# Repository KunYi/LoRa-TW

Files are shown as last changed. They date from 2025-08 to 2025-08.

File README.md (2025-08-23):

# LoRa-TW

**LoRa-TW** is a hardware project designed in **KiCAD** targeting LoRa applications in the Taiwan frequency band(AS923, 920MHz ~ 925MHz).
The design is based on the **Semtech SX1262** transceiver, optimized for robust operation in noisy RF environments.

## Project Purpose
This project aims to provide a reliable LoRa module reference design for Taiwan (center frequency **922.5 MHz**).
To improve receiver robustness, an external **SAW filter** is introduced in the RX path to mitigate interference from nearby cellular communication bands.

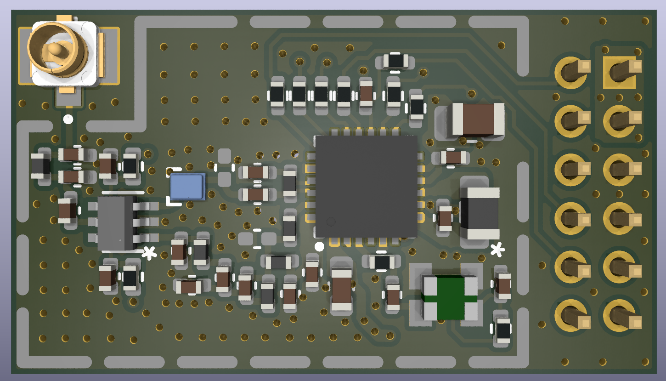
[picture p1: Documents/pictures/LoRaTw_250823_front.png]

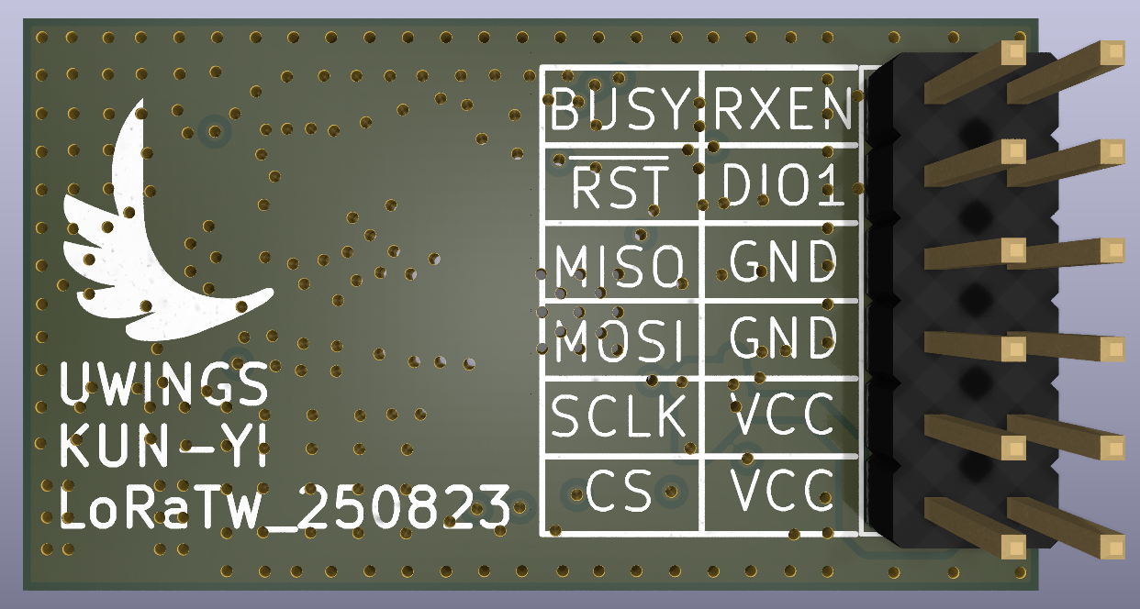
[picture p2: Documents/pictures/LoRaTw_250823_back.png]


## Key Features
- **RF Core**: Semtech SX1262
- **T/R Switch**: PSemi RF switch
- **Filtering**: QUALCOMM SAW filter (optimized for 922.5 MHz center frequency)
- **Powering**: DC-DC mode operation
- **Form Factor**: 12-pin 2.0mm breakout for easy integration

## Pinout
| Pin | Name | Description |
|-----|---|---|
| 1 | VDD | Power supply |
| 2 | CS | Chip Select |
| 3 | VDD | Power supply |
| 4 | SCLK | SPI Clock |
| 5 | GND | Ground |
| 6 | MOSI | SPI Data (Master Out) |
| 7 | GND | Ground |
| 8 | MISO | SPI Data (Master In) |
| 9 | DIO1 | Interrupt / IRQ |
| 10  | /RESET | Reset |
| 11  | RXEN | RX Enable (T/R Switch) |
| 12  | BUSY | SX1262 Busy status |

## Repository Contents
- `LoRa-TW.kicad_pcb` - KiCAD project
- `LoRa-TW.kicad_sch` – KiCAD schematic files
- `LoRa-TW.kicad_pcb` – KiCAD PCB layout files

## Author
**KUN-YI CHEN**,
📧 [kunyi.chen@gmail.com](mailto:kunyi.chen@gmail.com)

- **Current Version:** v1 (250823) – First release of the hardware design.
- **Status:** Schematic and PCB completed, awaiting validation and testing.
- **Planned Improvements:**
  - Conduct full RF testing and verification in Taiwan ISM band.
  - Optimize layout for improved RF isolation and matching.

## License
This project is licensed under the **CERN Open Hardware License v2 - Strongly Reciprocal (CERN-OHL-S-2.0)**.
You are free to use, modify, and distribute this design, but derivative works must also be shared under the same license.

For details, see the [LICENSE](LICENSE) file.

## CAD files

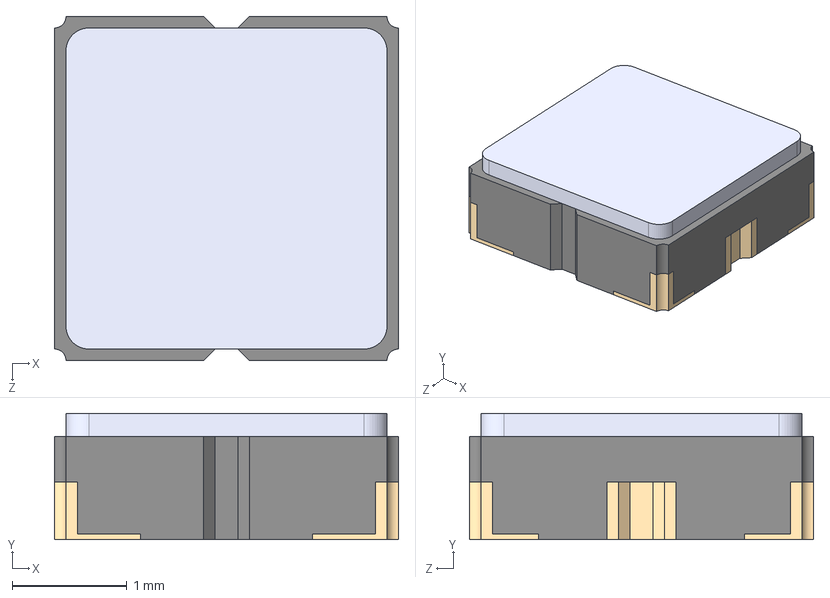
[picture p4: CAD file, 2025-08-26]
3D Models/SAW_3030.step
3.00 x 1.10 x 3.00 mm

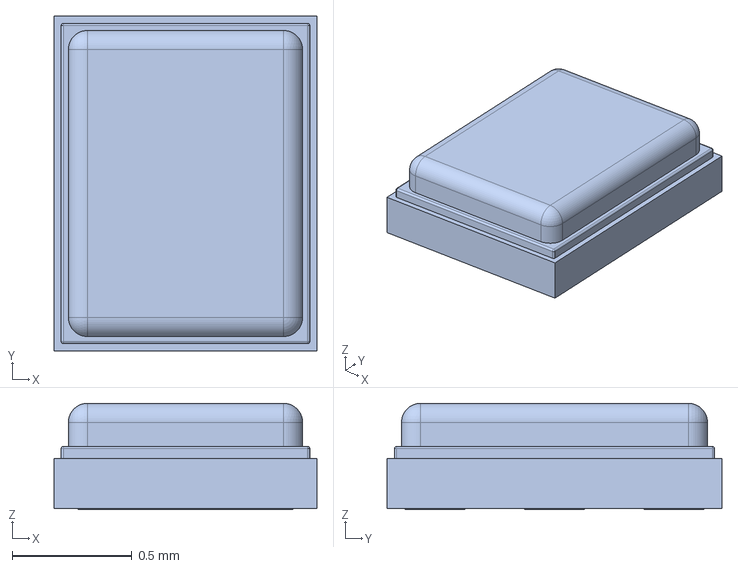
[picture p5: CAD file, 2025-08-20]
3D Models/SAW_1411.step
1.10 x 1.40 x 0.445 mm

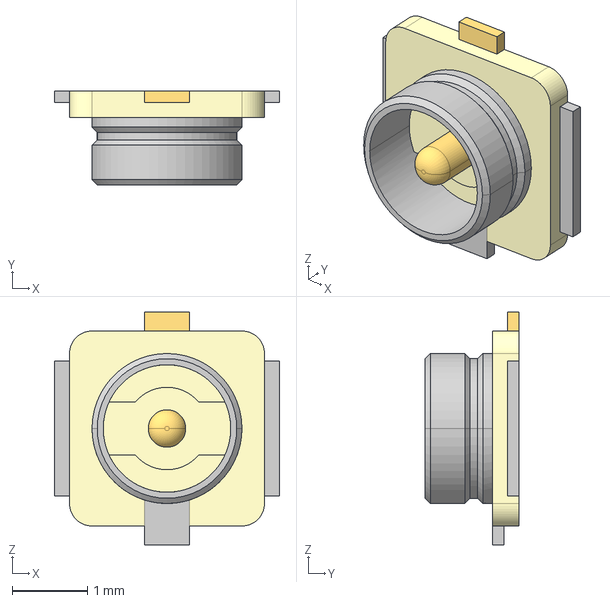
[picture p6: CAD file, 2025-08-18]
3D Models/U.FL-R-SMT-1.stp
3.00 x 1.25 x 3.10 mm

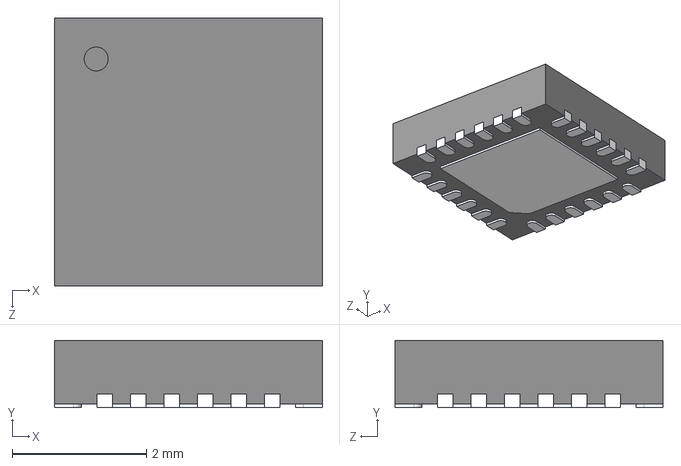
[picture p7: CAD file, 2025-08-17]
3D Models/SX1262IMLTRT.step
4.00 x 1.00 x 4.00 mm

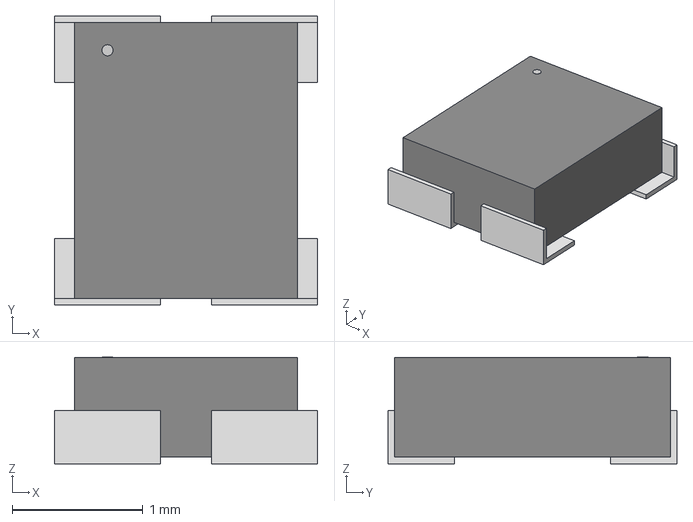
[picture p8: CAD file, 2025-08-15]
3D Models/NT2016SA-32M-END4263A_NDK.step
2.01 x 2.21 x 0.815 mm

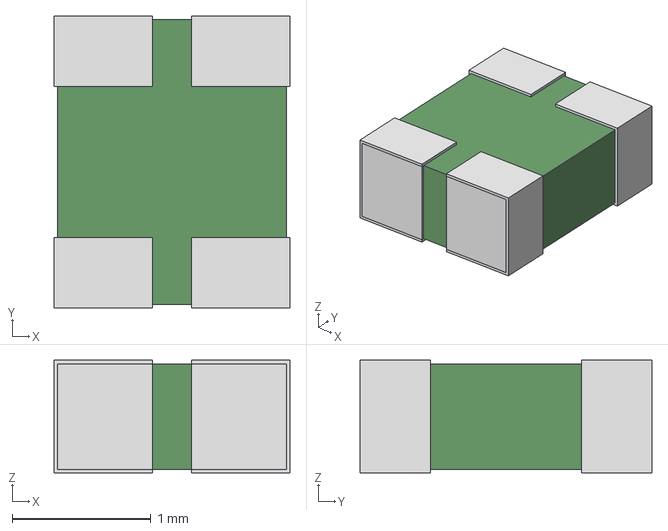
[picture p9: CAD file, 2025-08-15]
3D Models/NT2016SA_NDK.step
1.70 x 2.11 x 0.813 mm

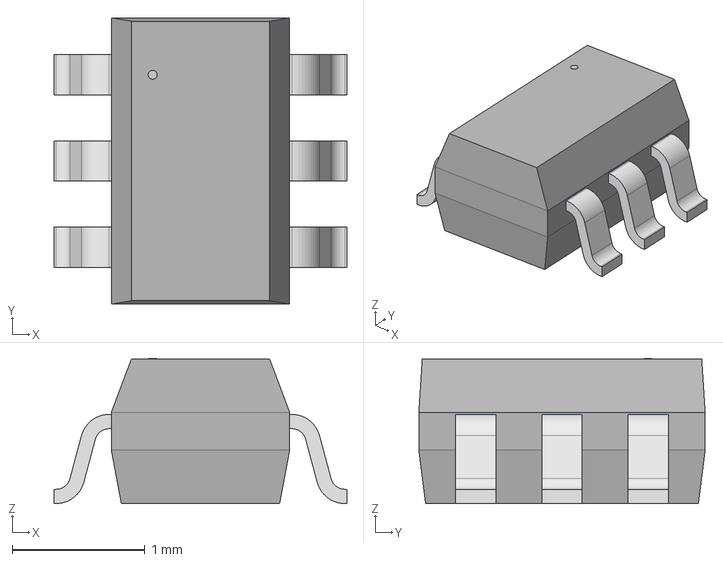
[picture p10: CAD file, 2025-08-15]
3D Models/SC-70-6_PSM.step
2.21 x 2.16 x 1.09 mm

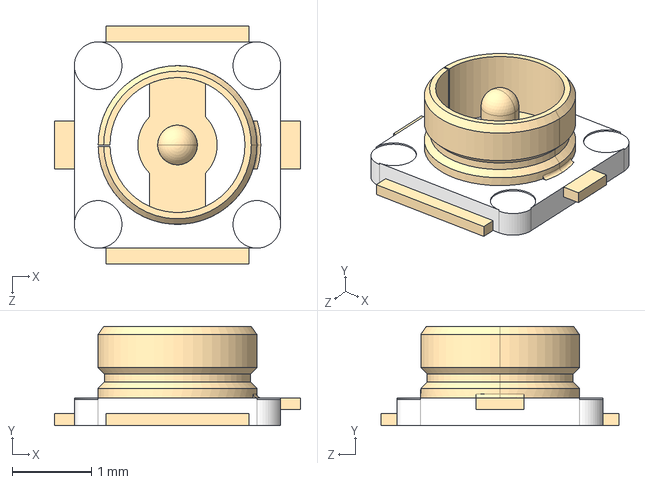
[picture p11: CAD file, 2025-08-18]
3D Models/20279-001E-03.step
3.10 x 1.25 x 3.00 mm

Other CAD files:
3D Models/SAW B2619 Filter.FCStd

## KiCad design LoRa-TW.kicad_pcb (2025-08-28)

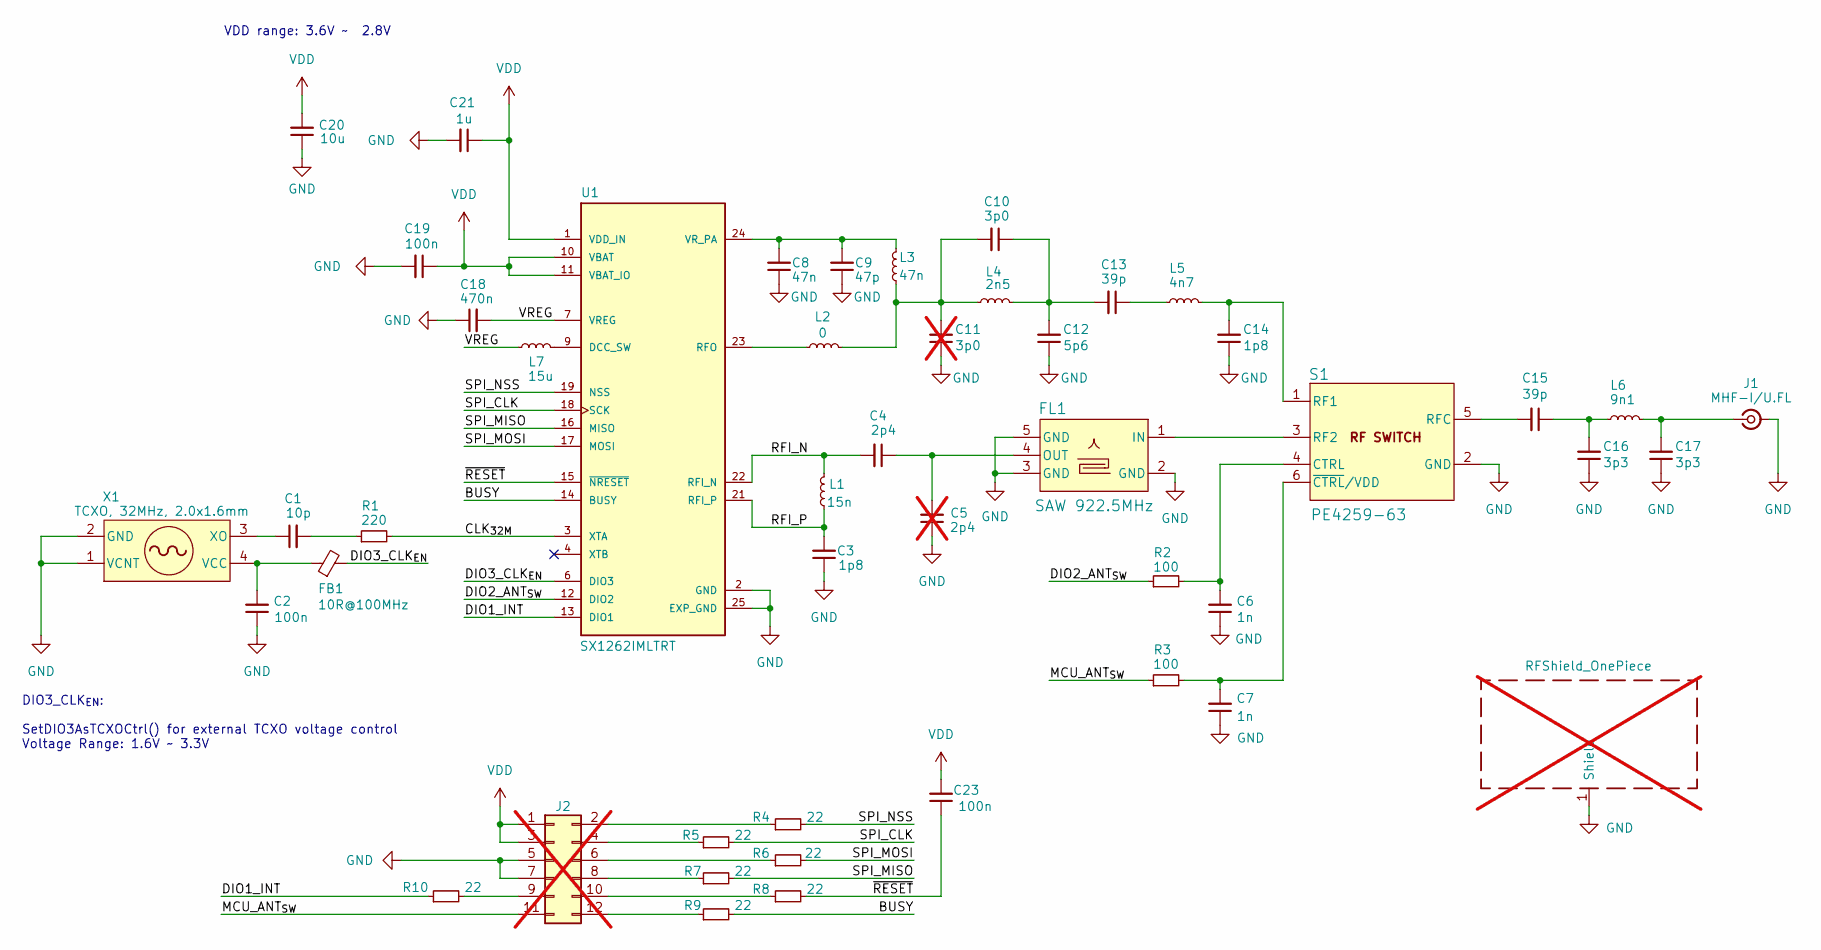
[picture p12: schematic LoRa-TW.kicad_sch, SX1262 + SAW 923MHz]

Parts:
C1: 10p; C_HF_0402_1005Metric; Part No GJM1555C1H100JB01D
C2, C19, C23: 100n; C_HF_0402_1005Metric; Part No GRM155R71H104KE14D
C3, C14: 1p8; C_HF_0402_1005Metric; Part No GJM1555C1H1R8BB01D
C4: 2p4; C_HF_0402_1005Metric; Part No GJM1555C1H2R4BB01D
C5: 2p4; C_HF_0402_1005Metric; Part No GJM1555C1H2R4BB01D; not fitted
C6, C7: 1n; C_HF_0402_1005Metric; Part No GRM155R72A102KA01D
C8: 47n; C_HF_0402_1005Metric; Part No GRM155R71C473KA01D
C9: 47p; C_HF_0402_1005Metric; Part No GJM1555C1H470JB01D
C10: 3p0; C_HF_0402_1005Metric; Part No GJM1555C1H3R0BB01D
C11: 3p0; C_HF_0402_1005Metric; Part No GJM1555C1H3R0BB01D; not fitted
C12: 5p6; C_HF_0402_1005Metric; Part No GJM1555C1H5R6CB01D
C13, C15: 39p; C_HF_0402_1005Metric; Part No GJM1555C1H390JB01D
C16, C17: 3p3; C_HF_0402_1005Metric; Part No GJM1555C1H3R3BB01D
C18: 470n; C_HF_0402_1005Metric; Part No GRM155R71A474KE01D
C20: 10u; C_0805_2012Metric; Part No GRM21BR71A106KA3L
C21: 1u; C_0603_1608Metric; Part No 0603B105K250CT
FB1: 10R@100MHz; R_HF_0402_1005Metric; Part No BLM15PG100SN1D
FL1: SAW 922.5MHz; SAW_1411; Part No TA2710AA1322
J1: MHF-I/U.FL; IPEX_20279-001E-03; Part No 20279-001E-03
J2: Conn_02x06_2.0mm; PinHeader_2x06_P2.00mm_Vertical; not fitted
J3: RFShield_OnePiece; ShieldCan; not fitted
L1: 15n; L_HF_0402_1005Metric; Part No LQW15AN15NH00D
L2: 0; L_HF_0402_1005Metric; Part No CRCW04020000Z0EDC
L3: 47n; L_HF_0402_1005Metric; Part No LQW15AN47NJ00D
L4: 2n5; L_HF_0402_1005Metric; Part No LQW15AN2N5C00D
L5: 4n7; L_HF_0402_1005Metric; Part No LQW15AN4N7C00D
L6: 9n1; L_HF_0402_1005Metric; Part No LQW15AN9N1H00D
L7: 15u; L_0805_2012Metric; Part No MLZ2012M150WT000
R1: 220; R_HF_0402_1005Metric; Part No CRCW0402220RJNED
R2, R3: 100; R_HF_0402_1005Metric; Part No CRCW0402100RJNED
R4, R5, R6, R7, R8, R9, R10: 22; R_HF_0402_1005Metric; Part No CRCW040222R0JNED
S1: PE4259-63; SC-70-6_PSM; Part No PE4259-63
U1: SX1262IMLTRT; PARTREV 1.1
X1: TCXO, 32MHz, 2.0x1.6mm; NT2016SA_NDK; Part No NT2016SA-32MHz-END4263A/NT2016SF-END426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

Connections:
/BUSY: R9.2, U1.14 (BUSY)
/CLK_{32M}: R1.2, U1.3 (XTA)
/DIO1_INT: R10.1, U1.13 (DIO1)
/DIO2_ANT_{SW}: R2.1, U1.12 (DIO2)
/DIO3_CLK_{EN}: FB1.2, U1.6 (DIO3)
/MCU_ANT_{SW}: J2.11, R3.1
/RFI_N: C4.2, L1.2, U1.22 (RFI_N)
/RFI_P: C3.2, L1.1, U1.21 (RFI_P)
/SPI_CLK: R5.2, U1.18 (SCK)
/SPI_MISO: R7.2, U1.16 (MISO)
/SPI_MOSI: R6.2, U1.17 (MOSI)
/SPI_NSS: R4.2, U1.19 (NSS)
/VREG: C18.2, L7.1, U1.7 (VREG)
/~RESET: C23.1, R8.2, U1.15 (~NRESET)
GND: C2.1, C3.1, C5.1, C6.1, C7.1, C8.1, C9.1, C11.1, C12.1, C14.1, C16.1, C17.1, C18.1, C19.2, C20.1, C21.2, FL1.2 (GND), FL1.3 (GND), FL1.5 (GND), J1.2, J1.3, J2.5, J2.7, J3.1 (Shield), S1.2 (GND), U1.2 (GND), U1.5 (GND), U1.8 (GND), U1.20 (GND), U1.25 (EXP_GND), X1.1 (VCNT), X1.2 (GND)
unnamed: C1.2, R1.1
unnamed: C10.1, C12.2, C13.2, L4.2
unnamed: C10.2, C11.2, L2.2, L3.1, L4.1
unnamed: C13.1, L5.1
unnamed: C15.1, C16.2, L6.1
unnamed: C17.2, J1.1, L6.2
unnamed: FL1.1 (IN), S1.3 (RF2)
unnamed: C4.1, C5.2, FL1.4 (OUT)
unnamed: J2.2, R4.1
unnamed: J2.4, R5.1
unnamed: J2.6, R6.1
unnamed: J2.8, R7.1
unnamed: J2.9, R10.2
unnamed: J2.10, R8.1
unnamed: J2.12, R9.1
unnamed: C6.2, R2.2, S1.4 (CTRL)
unnamed: C14.2, L5.2, S1.1 (RF1)
unnamed: C15.2, S1.5 (RFC)
unnamed: C7.2, R3.2, S1.6 (~CTRL/VDD)
unnamed: L7.2, U1.9 (DCC_SW)
unnamed: L2.1, U1.23 (RFO)
unnamed: C8.2, C9.2, L3.2, U1.24 (VR_PA)
unnamed: C2.2, FB1.1, X1.4 (VCC)
unnamed: C1.1, X1.3 (XO)
VDD: C19.1, C20.2, C21.1, C23.2, J2.1, J2.3, U1.1 (VDD_IN), U1.10 (VBAT), U1.11 (VBAT_IO)

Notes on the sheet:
DIO3_CLK_{EN}: SetDIO3AsTCXOCtrl() for external TCXO voltage control Voltage Range: 1.6V ~ 3.3V
VDD range: 3.6V ~ 2.8V

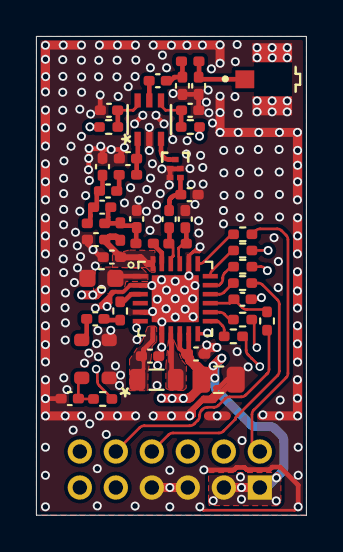
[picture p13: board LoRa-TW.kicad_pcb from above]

Board: 4 copper layers, 15.0 x 26.6 mm, 47 parts (1 on the bottom side), 40 nets.

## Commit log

2025-08-15 import basice components symbol/footprint
    [LoRa-TW.kicad_pcb, LoRa-TW.kicad_sch, NT2016SA_NDK.step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]
2025-08-15 Add some datasheet and step file
    - Update NT2016SA Step file
    - Add 32MHz TCXO NT2016SA/TG-5006CJ datasheet
    [NT2016SA-32M-END4263A_NDK.step]
2025-08-17 update receive of schematic
    - update symbol
    - place rx path components
    [LoRa-TW.kicad_pcb, LoRa-TW.kicad_sch, SX1262IMLTRT.step]
2025-08-17 update transmit of schematic
    - update TX path
    - correct some components properties
    [LoRa-TW.kicad_pcb]
2025-08-18 add IPEX/U.FL 3D Model
    - add I-PEX MHF-I Datasheet
    - add U.FL and MHF-I 3D Model
    [20279-001E-03.step, U.FL-R-SMT-1.stp]
2025-08-18 add I-PEX MHF-I RF connector sym/fp
2025-08-18 update schematic for power input
    [LoRa-TW.kicad_pcb]
2025-08-18 add project owner 0402 footprint for reduce area
2025-08-18 update schematic & pcb for new footprint
    [LoRa-TW.kicad_pcb]
2025-08-19 add JLC PCB stack
2025-08-19 Add SAW Filter 3D model by FreeCAD
    [SAW B2619 Filter.FCStd, SAW B2619 Filter.step]
2025-08-19 add new JLC PCB stack with PP-7628
2025-08-20 update SAW Filter properties with 3D Model
    [LoRa-TW.kicad_pcb, SAW B2619 Filter.FCStd, SAW B2619 Filter.step]
2025-08-20 update layout for RF parts
    [LoRa-TW.kicad_pcb, LoRa-TW.kicad_sch]
2025-08-21 add shielding can
    [LoRa-TW.kicad_sch]
2025-08-21 update layout part
    [LoRa-TW.kicad_pcb]
2025-08-22 fine turning layout
    [LoRa-TW.kicad_pcb]
2025-08-22 update RXEN/TXEN information in schematic
    [LoRa-TW.kicad_sch]
2025-08-22 update layout of pcb
    [LoRa-TW.kicad_pcb]
2025-08-22 update all via hole to diameter 0.5mm from 0.48mm
    [LoRa-TW.kicad_pcb]
2025-08-22 update 15uH for sch and pcb
    [LoRa-TW.kicad_pcb, LoRa-TW.kicad_sch]
2025-08-23 prepare for BOM generation
    [LoRa-TW.kicad_pcb, LoRa-TW.kicad_sch]
2025-08-23 add new SAW filter for ISM 915MHz for reference
2025-08-23 update footprints
2025-08-23 update footprint of PCB for DRC check and fine turning
    [LoRa-TW.kicad_pcb]
2025-08-24 update description of components
    [LoRa-TW.kicad_sch]
2025-08-24 sych. properties of schematic to pcb
    [LoRa-TW.kicad_pcb]
2025-08-24 adjustion gen. column of BOM options
2025-08-25 optimization DC2DC layout
    [LoRa-TW.kicad_pcb]
2025-08-25 optimization layout
    [LoRa-TW.kicad_pcb]
2025-08-26 update footprints and 3D Models
    - rename or update some properties
    - update shielding metal can
    [SAW_1411.step, SAW_3030.step]
2025-08-26 update SAW filter to use TST TA2710AA1322
    [LoRa-TW.kicad_sch]
2025-08-26 update and fine turning
    [LoRa-TW.kicad_pcb]
2025-08-28 PCB release version
    Add LCSC part number into footprint properties
    [LoRa-TW.kicad_pcb]
2025-08-28 change datasheet of SAW filter location
2025-08-28 update SAW Filter 3030 symbol & update 3D model
2025-08-28 add relase for JLC PCB/SMT
    [LoRa-TW-CuBottom.gbr, LoRa-TW-CuIn1.gbr, LoRa-TW-CuIn2.gbr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]
2025-08-29 add 0R_Jump sym & footprint
